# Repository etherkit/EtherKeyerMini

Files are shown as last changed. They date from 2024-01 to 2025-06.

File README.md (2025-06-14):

# EtherKeyer Mini

A simple keyer that does the basic functions that you need.

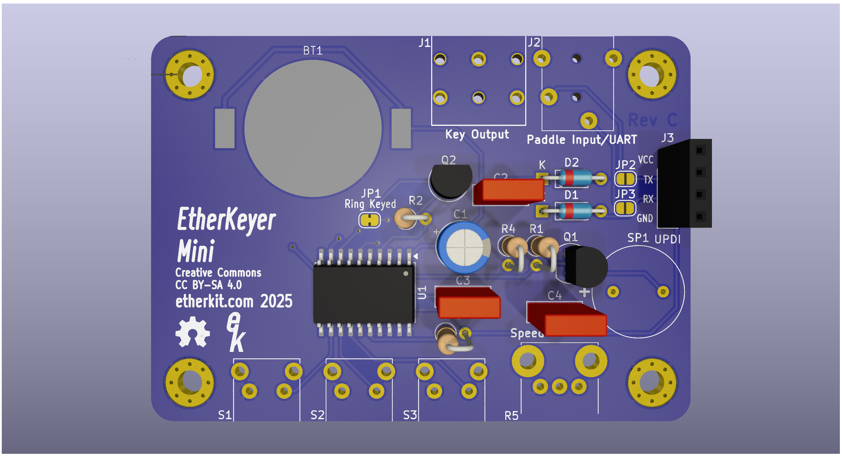
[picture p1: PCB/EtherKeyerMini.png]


## Requirements

In order to program the message memories, change parameters other than the keyer speed, and update the firmware, you'll need a serial terminal that can connect to the 5 V TTL UART on EtherKeyer Mini via the 3.5 mm TRRS paddle jack. The Etherkit UART Adapter board has a USB-C connection for your PC and the requisite 3.5 mm TRRS jack, so that all that you need to connect to EtherKeyer Mini is a 3.5 mm TRRS cable.

A CR2032 lithium coin cell is required for powering EtherKeyer Mini.

## Functions

### Speed Potentiometer

The knob control on the right side of the front of EtherKeyer Mini controls the keyer speed, from a minimum of 5 WPM to a maximum of 40 WPM. This control can be adjusted at any time and responds immediately.

### Pushbuttons

#### Short Press

Cancel any message playback by pressing any button or paddle.

- 1 - Play Message Memory 1
- 2 - Play Message Memory 2
- 3 - Play Message Memory 3

#### Long Press

- 1 - Tune Mode (press any key to exit)
- 2 - Toggle Internal Sidetone
- 3 - Enter/Exit UART Mode

### UART Mode

The format for interacting with EtherKeyer Mini via the UART is very simple. In order to place EtherKeyer Mini into UART mode, press and hold button 3 for at least one second. If your serial terminal is open when you do this, you'll get a greeting from EtherKeyer Mini to let you know it is ready for commands.

Each message memory has a maximum size of 40 characters.

Exit UART mode by pressing and holding button 3 again for at least one second, or issue the ```X:``` command in the serial terminal.

#### Serial Terminal Parameters

19200 baud, send New Line only, no flow control.

#### Query

- ```W?``` - Keyer speed
- ```1?``` - Message memory 1
- ```2?``` - Message memory 2
- ```3?``` - Message memory 3

#### Parameter Set

- ```1:<message>``` - Message memory 1
- ```2:<message>``` - Message memory 2
- ```3:<message>``` - Message memory 3
- ```X:``` - Exit UART Mode
- ```R:``` - Reverse Paddle Terminals
- ```N:``` - Normal Paddle Terminals
- ```A:``` - Set Iambic A Mode
- ```B:``` - Set Iambic B Mode
- ```S:``` - Sidetone On
- ```O:``` - Sidetone Off

## Firmware Updates

__Please see the Requirements section above for the hardware necessary for the UART adapter.__

EtherKeyer Mini uses an ATtiny3226 microcontroller with the Optiboot bootloader pre-installed. You can use load new firmware onto EtherKeyer Mini via a UART adapter connected to the paddle jack (the easiest way to do so is using the Etherkit UART Adapter board with a 3.5 mm TRRS cable). You can also use a standard USB-UART adapter connected to jack J3 to program the ATtiny3226 via UPDI protocol.

Programming via the paddle jack is accomplished using the Arduino IDE using the [megaTinyCore](https://github.com/SpenceKonde/megaTinyCore) board support package. Use [this link](https://github.com/SpenceKonde/megaTinyCore/blob/master/Installation.md) for instructions on how to add this board support package to your Arduino IDE. Once you have added the board support package, connect your UART adapter to your PC. In Arduino IDE, select the "ATtiny3226/1626/826/426 w/Optiboot" as your board and port corresponding to your programming UART adapter. Make sure to set all of the specific board settings in the Tools menu of Arduino IDE to those shown below:

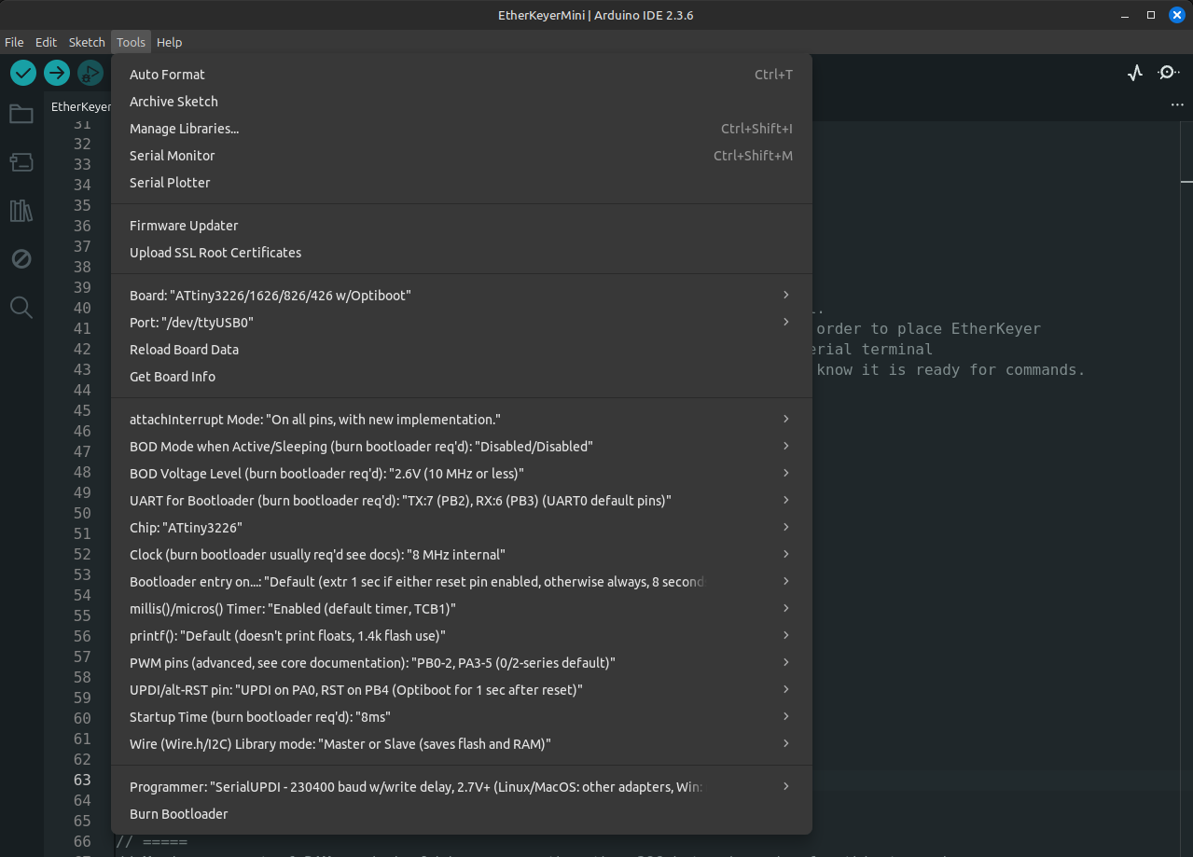
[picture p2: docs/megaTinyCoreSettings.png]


Once you have all of these settings correct, you can load the EtherKeyerMini.ino sketch into the Arduino IDE and then use the Sketch > Upload menu command or use the upload button on the toolbar.

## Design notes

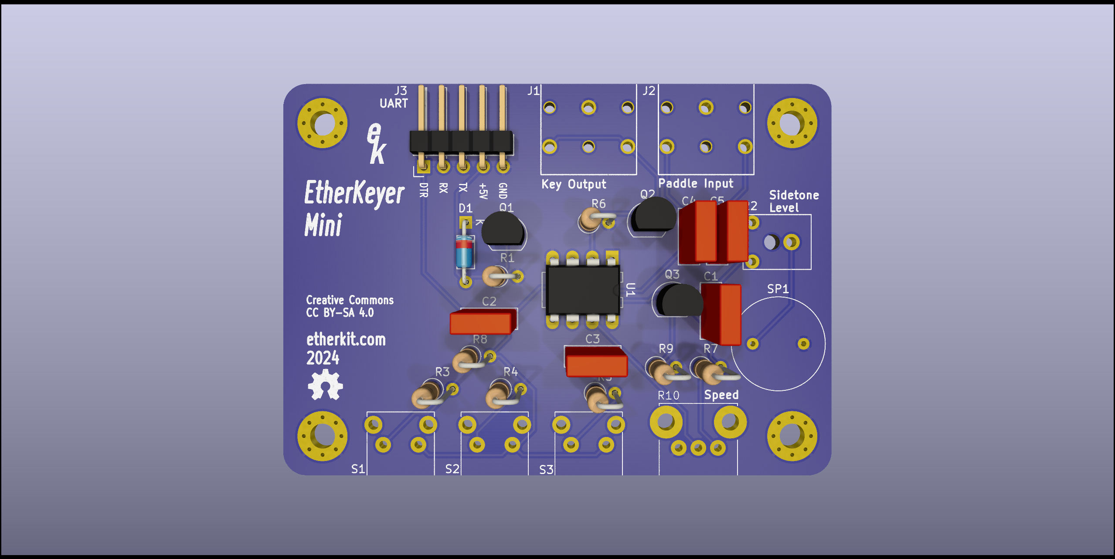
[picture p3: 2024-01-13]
docs/EtherKeyerMini.png

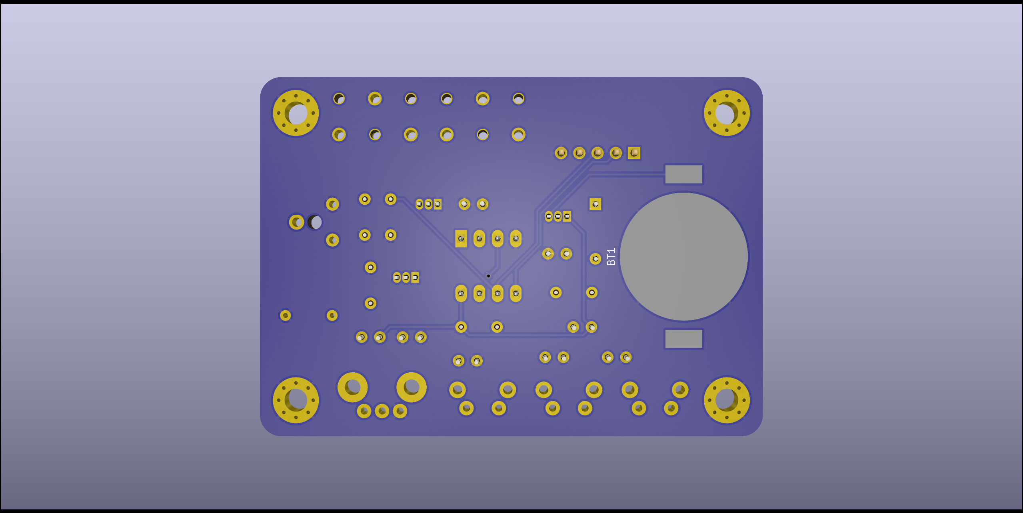
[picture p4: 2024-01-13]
docs/EtherKeyerMiniBack.png

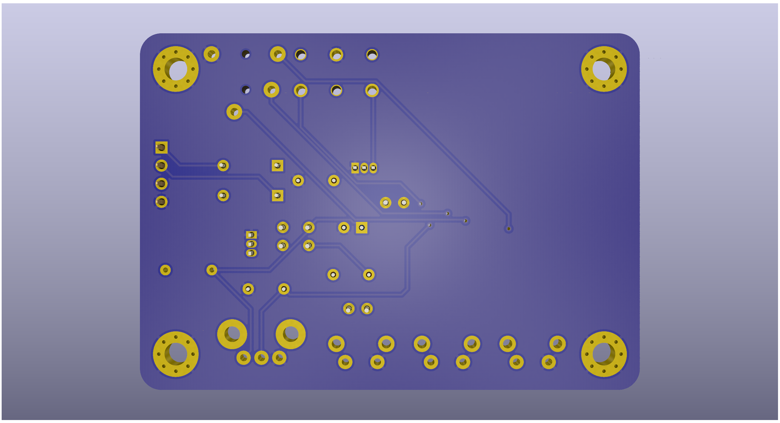
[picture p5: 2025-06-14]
PCB/EtherKeyerMiniBack.png

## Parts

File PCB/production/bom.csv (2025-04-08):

Designator | Footprint | Quantity | Value | LCSC Part #
BT1 | Linx_BAT-HLD-001 | 1 | CR2032
C1 | CP_Radial_D6.3mm_P2.50mm | 1 | 4.7u
C2, C3, C4 | C_Rect_L7.0mm_W2.5mm_P5.00mm | 3 | 100n
D1, D2 | D_DO-35_SOD27_P7.62mm_Horizontal | 2 | 1N5711
J1 | Kycon_STX-3120-3B | 1 | Key Output
J2 | SameSky_SJ-43514 | 1 | Paddle Input/UART
J3 | PinSocket_1x04_P2.54mm_Vertical | 1 | UPDI
Q1, Q2 | TO-92_Inline | 2 | 2N4401
R1, R2, R4 | R_Axial_DIN0207_L6.3mm_D2.5mm_P2.54mm_Vertical | 3 | 10k
R3 | R_Axial_DIN0207_L6.3mm_D2.5mm_P2.54mm_Vertical | 1 | 470
R5 | Bournes_PTV09A | 1 | 1M
S1, S2, S3 | C&K_PTS645VH832LFS | 3 | PUSHBUTTON_TACTILE
SP1 | PUI_AT-1224-TWT-12V-2-R | 1 | Piezo Speaker
U1 | SOIC-20W_7.5x12.8mm_P1.27mm | 1 | ATtiny3226-S

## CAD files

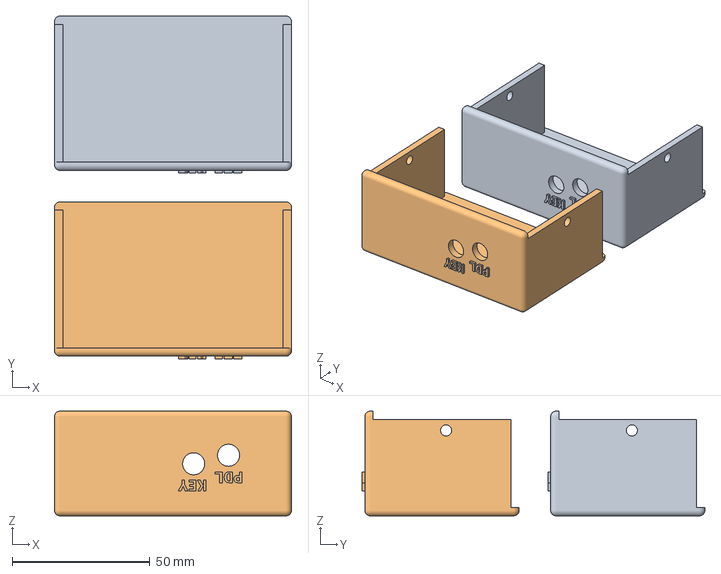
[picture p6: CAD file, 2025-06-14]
mech/EtherKeyerMiniCaseTopNew-Case Top.3mf
86.0 x 124.4 x 38.0 mm

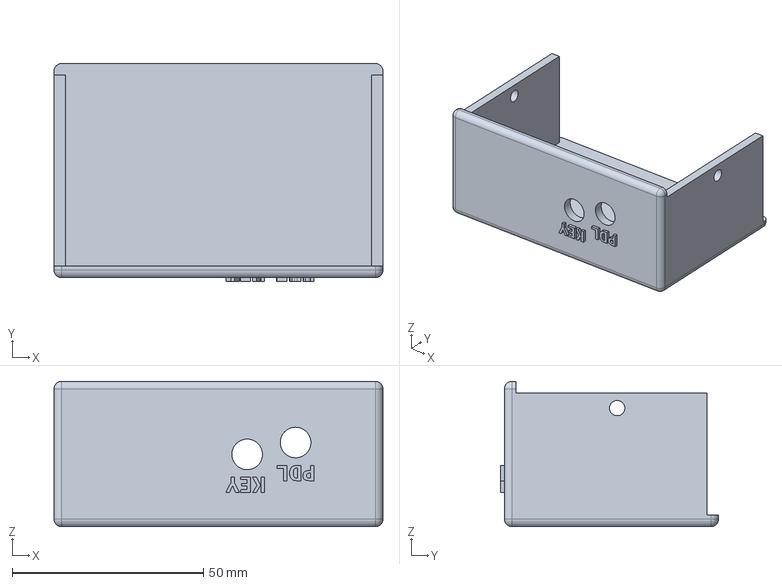
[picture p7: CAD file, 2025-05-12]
mech/EtherKeyerMiniCaseTopNew.FCStd
86.0 x 57.0 x 38.0 mm

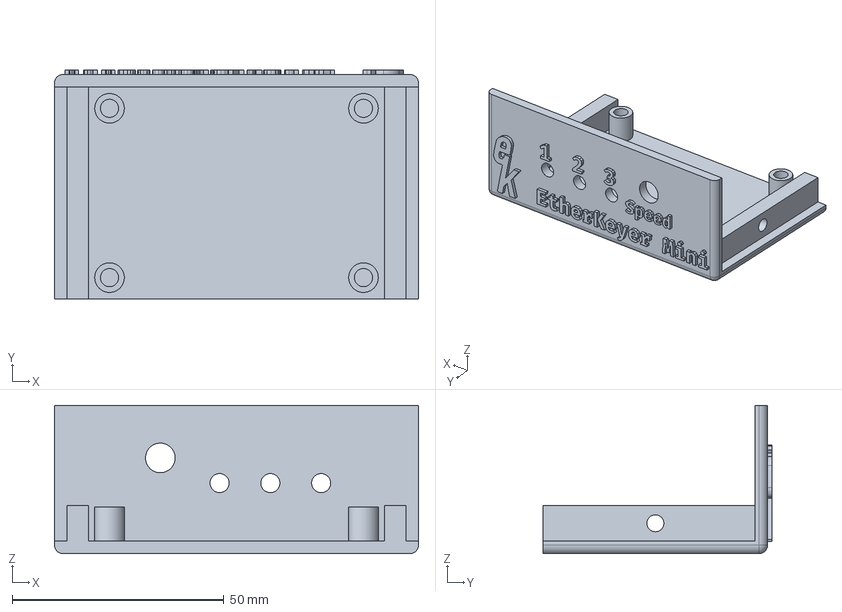
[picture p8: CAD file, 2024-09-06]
mech/EtherKeyerMiniCaseBottomNew.FCStd
86.0 x 54.0 x 35.0 mm

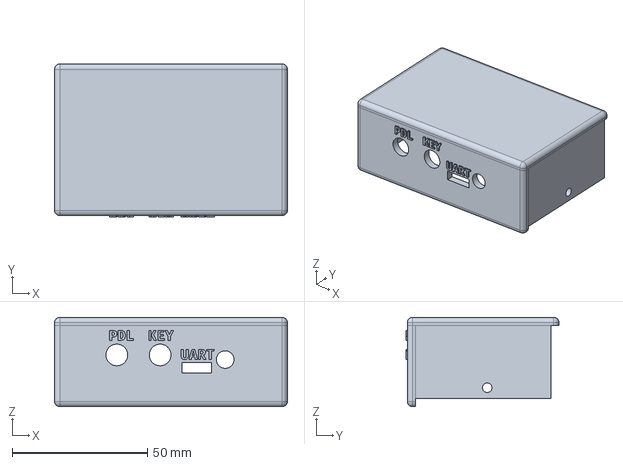
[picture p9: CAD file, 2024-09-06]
mech/EtherKeyerMiniCaseTop.FCStd
86.0 x 56.5 x 33.0 mm

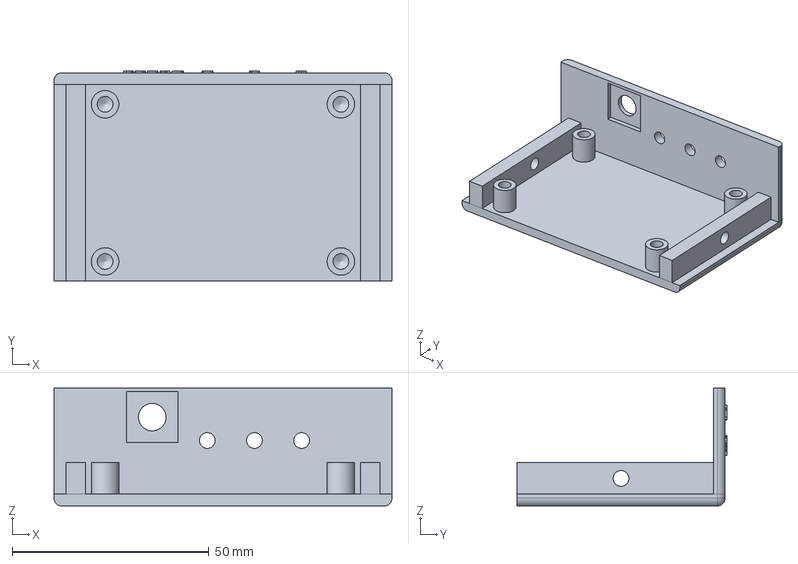
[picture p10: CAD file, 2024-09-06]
mech/EtherKeyerMiniCaseBottom.FCStd
86.0 x 53.5 x 30.0 mm
Case Bottom
ShapeString004
ShapeString005
ShapeString006

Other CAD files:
mech/EtherKeyerMiniCaseBottomNew-Case Bottom.3mf
mech/EtherKeyerMiniCaseBottom.stl
mech/EtherKeyerMiniCaseTop.stl

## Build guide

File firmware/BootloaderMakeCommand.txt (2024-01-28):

make MCU=attiny85 WDTO=2S F_CPU=8000000L BAUD_RATE=57600 SWIO=1 RX=AtmelPB1 TX=AtmelPB0 VBL=1 EEPROM=0 CHIP_ERASE=0 URPROTOCOL=1 BLINK=0 AUTOFRILLS=0,6,4,3,2 NAME=urboot_t85_2s_i8m0_57k6_swio_rxb1_txb0_no-led

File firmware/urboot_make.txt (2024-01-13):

make MCU=attiny85 WDTO=2S F_CPU=8000000L BAUD_RATE=57600 SWIO=1 RX=AtmelPB1 TX=AtmelPB0 VBL=1 PROTECTRESET=1 EEPROM=0 CHIP_ERASE=0 URPROTOCOL=1 BLINK=0 AUTOFRILLS=0,6,4,3,2 NAME=urboot_t85_2s_i8m0_57k6_swio_rxb4_txb3_no-led_pr

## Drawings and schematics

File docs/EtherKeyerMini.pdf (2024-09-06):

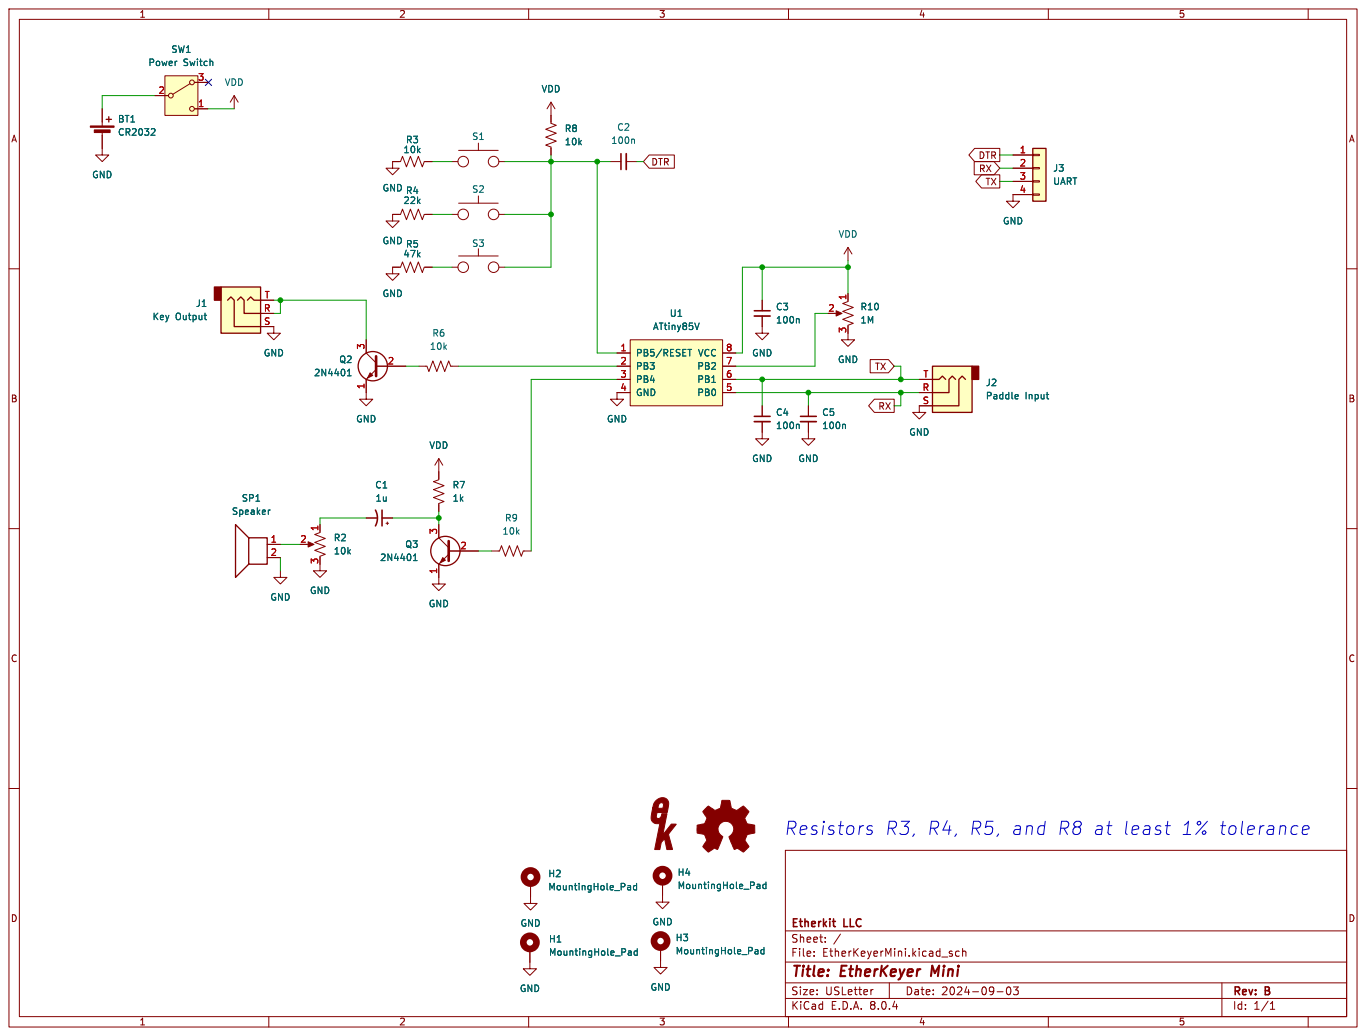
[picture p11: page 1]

TX Resistors R3, R4, R5, and R8 at least 1% tolerance

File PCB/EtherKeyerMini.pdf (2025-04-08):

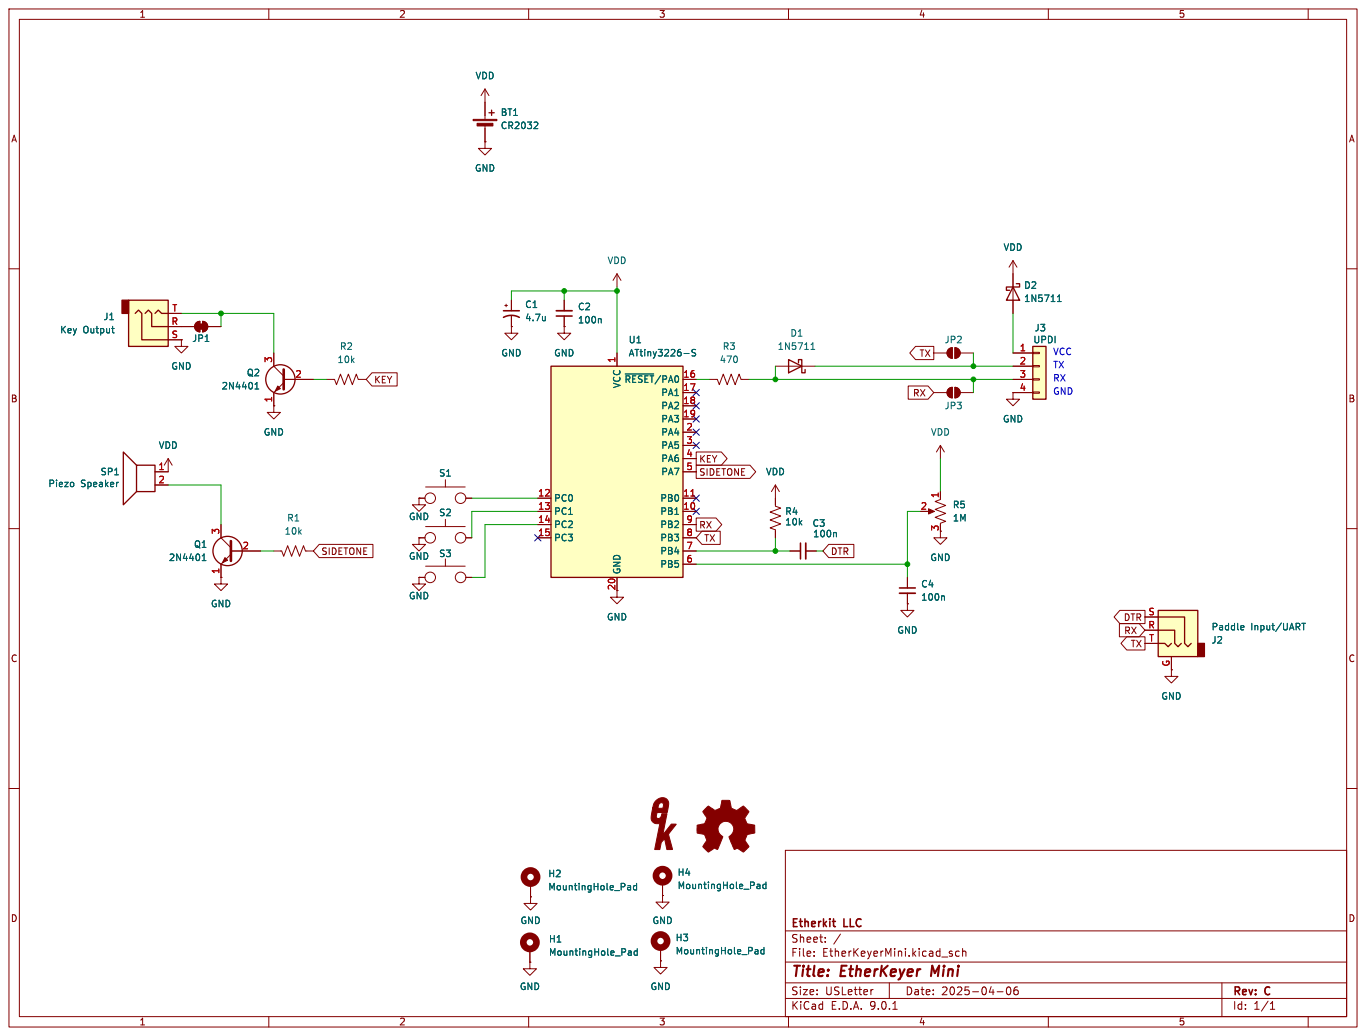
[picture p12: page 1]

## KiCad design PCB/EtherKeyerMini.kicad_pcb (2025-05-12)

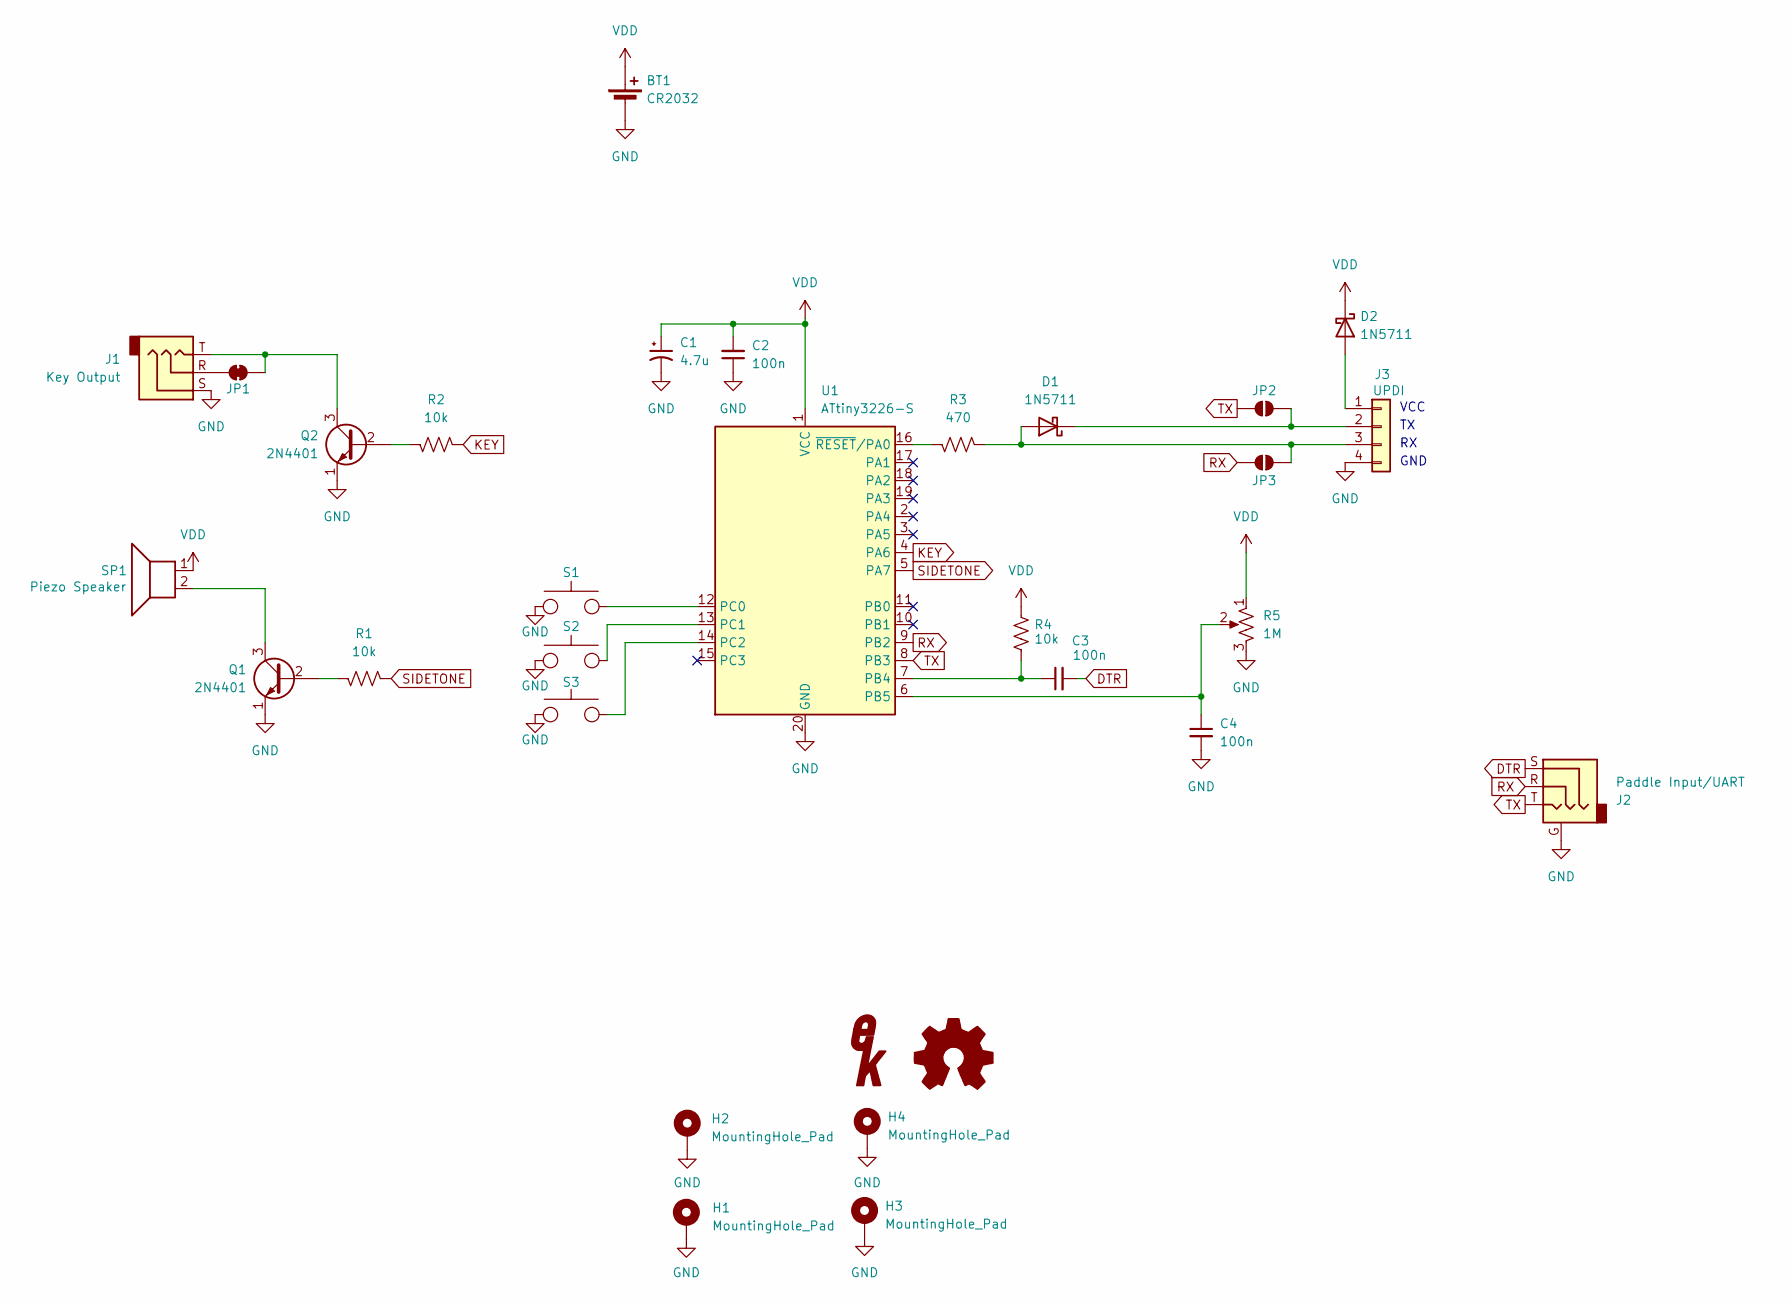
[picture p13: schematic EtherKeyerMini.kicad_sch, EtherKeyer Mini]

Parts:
BT1: CR2032; Linx_BAT-HLD-001
C1: 4.7u; CP_Radial_D6.3mm_P2.50mm
C2, C3, C4: 100n; C_Rect_L7.0mm_W2.5mm_P5.00mm
D1, D2: 1N5711; D_DO-35_SOD27_P7.62mm_Horizontal
G1: LOGO; EtherkitLogoSmall
H1, H2, H3, H4: MountingHole_Pad; MountingHole_3.2mm_M3_Pad_Via
J1: Key Output; Kycon_STX-3120-3B
J2: Paddle Input/UART; SameSky_SJ-43514
J3: UPDI; PinSocket_1x04_P2.54mm_Vertical
JP1: SolderJumper_2_Bridged; SolderJumper-2_P1.3mm_Bridged_RoundedPad1.0x1.5mm
JP2, JP3: SolderJumper_2_Bridged; SolderJumper-2_P1.3mm_Open_RoundedPad1.0x1.5mm
Q1, Q2: 2N4401; TO-92_Inline
R1, R2, R4: 10k; R_Axial_DIN0207_L6.3mm_D2.5mm_P2.54mm_Vertical
R3: 470; R_Axial_DIN0207_L6.3mm_D2.5mm_P2.54mm_Vertical
R5: 1M; Bournes_PTV09A
S1, S2, S3: PUSHBUTTON_TACTILE; C&K_PTS645VH832LFS
SP1: Piezo Speaker; PUI_AT-1224-TWT-12V-2-R
SYM1: Logo_Open_Hardware_Small; OSHWLogo4mm
U1: ATtiny3226-S; SOIC-20W_7.5x12.8mm_P1.27mm

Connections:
DTR: C3.2, J2.S
GND: BT1.2 (-), C1.2, C2.1, C4.2, H1.1, H2.1, H3.1, H4.1, J1.S, J2.G, J3.4, Q1.1 (E), Q2.1 (E), R5.3, S1.1, S2.1, S3.1, U1.20 (GND)
KEY: R2.2, U1.4 (PA6)
unnamed: D1.2 (A), J3.3, JP3.2 (B), R3.2
unnamed: D1.1 (K), J3.2, JP2.2 (B)
unnamed: D2.2 (A), J3.1
unnamed: J1.R, JP1.1 (A)
unnamed: J1.T, JP1.2 (B), Q2.3 (C)
unnamed: Q1.2 (B), R1.1
unnamed: Q1.3 (C), SP1.2
unnamed: Q2.2 (B), R2.1
unnamed: C3.1, R4.2, U1.7 (PB4)
unnamed: C4.1, R5.2, U1.6 (PB5)
unnamed: S1.2, U1.12 (PC0)
unnamed: S2.2, U1.13 (PC1)
unnamed: S3.2, U1.14 (PC2)
unnamed: R3.1, U1.16 (~RESET/PA0)
RX: J2.R, JP3.1 (A), U1.9 (PB2)
SIDETONE: R1.2, U1.5 (PA7)
TX: J2.T, JP2.1 (A), U1.8 (PB3)
VDD: BT1.1 (+), C1.1, C2.2, D2.1 (K), R4.1, R5.1, SP1.1, U1.1 (VCC)

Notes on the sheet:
GND
VCC

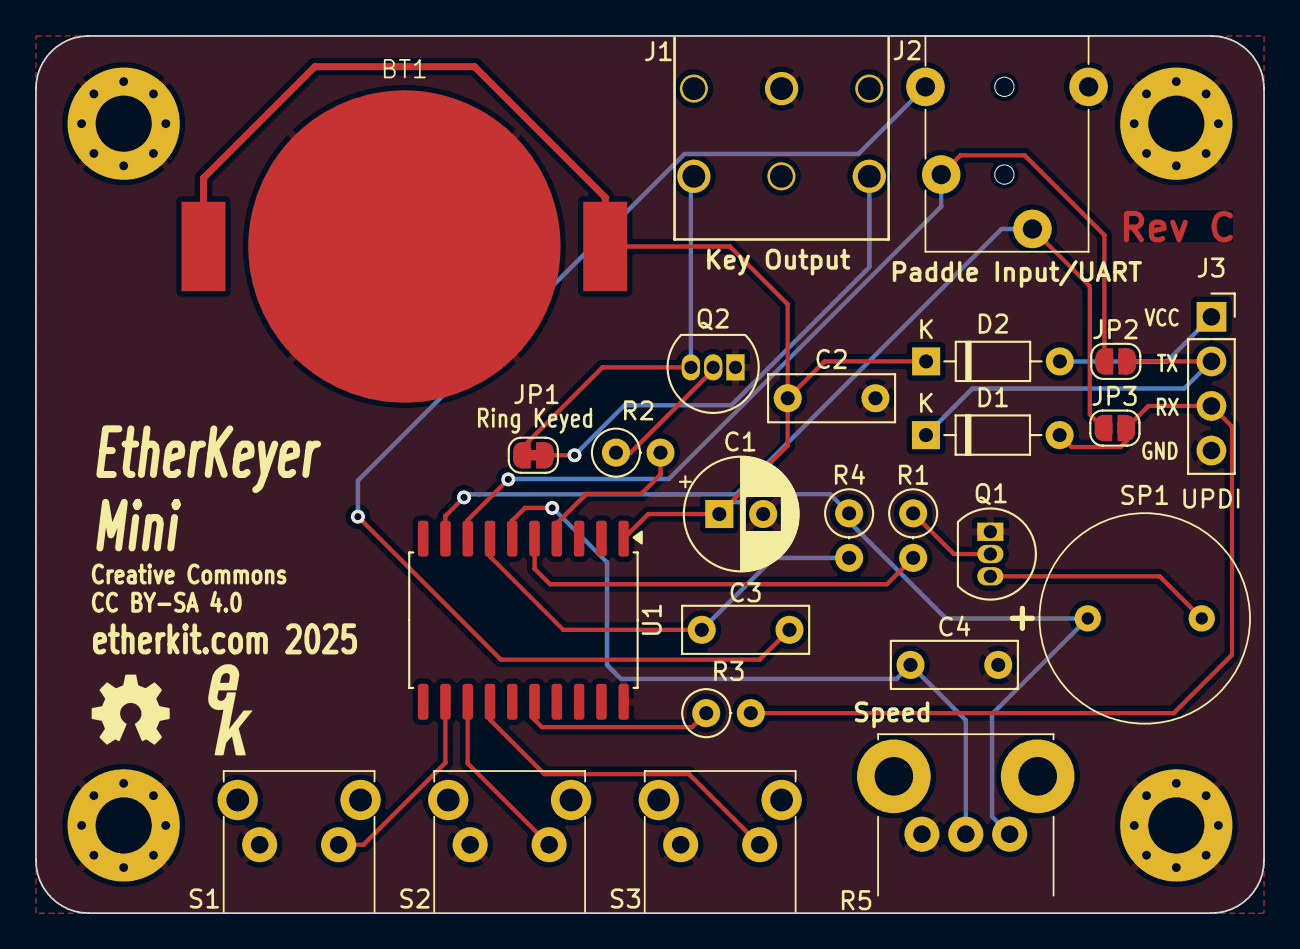
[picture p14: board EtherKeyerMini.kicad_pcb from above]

Board: 2 copper layers, 70.0 x 50.0 mm, 31 parts (0 on the bottom side), 21 nets.

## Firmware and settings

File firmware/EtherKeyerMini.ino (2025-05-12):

// EtherKeyer Mini
// 
// Jason Milldrum, NT7S
// Etherkit LLC
//
// This work is licensed under CC BY-SA 4.0
//
// Last Revision: 11 May 2025
// For Rev C PCB
//
// A basic memory Morse Code keyer for use with paddles.
// Keyer speed is adjustable via potentiometer. Three message memories with dedicated playback
// buttons are provided. Message memory programming and other parameter settings are done via
// serial terminal access at 19200 baud.
//
// Libraries Used
// ==============
// Etherkit Morse (Library Manager)
// Arduino Timer (Library Manager)
//
// Pushbuttons
// ===========
//
// Short Press
// -----------
// Cancel any message playback by pressing any button or paddle.
//
// * 1 - Play Message Memory 1
// * 2 - Play Message Memory 2
// * 3 - Play Message Memory 3
//
// Long Press
// ----------
// * 1 - Tune Mode (press any key to exit)
// * 2 - Toggle Internal Sidetone
// * 3 - Enter/Exit UART Mode
//
// Serial commands
// ===============
// Serial terminal parameters: 19200 baud, send New Line only, no flow control.
// The format for interacting with EtherKeyer via the UART is very simple. In order to place EtherKeyer
// into UART mode, press and hold button 3 for at least one second. If your serial terminal
// is open when you do this, you'll get a greeting from EtherKeyer to let you know it is ready for commands.
//
// Query
// -----
// W?     Keyer speed
// 1?     Message memory 1
// 2?     Message memory 2
// 3?     Message memory 3
//
// Parameter Set
// -------------
// 1:<message>     Message memory 1
// 2:<message>     Message memory 2
// 3:<message>     Message memory 3
// X:              Exit UART Mode
// R:              Reverse Paddle Terminals
// N:              Normal Paddle Terminals
// A:              Set Iambic A Mode
// B:              Set Iambic B Mode
// S:              Sidetone On
// O:              Sidetone Off
//
// Notes
// =====
// Maximum amount of RAM used should be no more than than 386 bytes in order for this to work

#include <stdint.h>
#include <Morse.h>
#include <arduino-timer.h>
#include <EEPROM.h>
#include <avr/interrupt.h>
#include <avr/sleep.h>
#include <avr/power.h>
#include <avr/wdt.h>

#define FIRMWARE_VERSION "11 May 2025"

// Pin defines
#define SPEED_INPUT PIN_PB5
#define PADDLE_RING PIN_PB2  // Typical config, ring == DAH
#define PADDLE_TIP PIN_PB3   // Typical config, tip == DIT
#define BUTTON_S1 PIN_PC0
#define BUTTON_S2 PIN_PC1
#define BUTTON_S3 PIN_PC2
#define KEY_OUTPUT PIN_PA6
#define SIDETONE_OUTPUT PIN_PA7

// Defaults
#define DEFAULT_SIDETONE_FREQ 600
#define DEFAULT_KEYER_SPEED 20

// Limits
#define KEYER_SPEED_LOWER 5
#define KEYER_SPEED_UPPER 40
#define BUTTON_PRESS_SHORT 10
#define BUTTON_PRESS_LONG 1000
#define SLEEP_TIME 3000  // In milliseconds, has to be long enough to not go to sleep during a long button press

// EEPROM Addresses
// Why not just use a struct for all of EEPROM? RAM is too scarce to work with the whole struct at once.
// So, we only load one param at a time. A bit cumbersome and not very foolproof, but we have our limits.
#define EEP_M1_ADDR 0  // Message memory 3 string, 40 chars plus terminator
#define EEP_M2_ADDR 41  // Message memory 3 string, 40 chars plus terminator
#define EEP_M3_ADDR 82  // Message memory 3 string, 40 chars plus terminator
#define EEP_PADDLE_REV 123  // Paddle reverse, 1 byte (uint8_t)
#define EEP_SIDETONE_FREQ 124  // Sidetone frequency, 2 bytes (uint16_t)
#define EEP_SPEED_LOWER 126  // Keyer speed lower limit, 1 byte (uint8_t)
#define EEP_SPEED_UPPER 127  // Keyer speed upper limit, 1 byte (uint8_t)
#define EEP_KEYER_MODE 128  // Keyer mode, 1 byte (uint8_t)
#define EEP_SIDETONE_ON 129  // Sidetone active, 1 byte (uint8_t)

// Enumerations
enum class KeyerState {IDLE, DIT, DAH, DITIDLE, DAHIDLE, CHARSPACE, PLAYBACK, ANNUNCIATE, UART, TUNE};
enum class Button {NONE, S1, S2, S3, S1S2, S2S3, S1S3, HOLD};
enum class Iambic {A, B};

// Global variables
uint32_t keyer_speed = DEFAULT_KEYER_SPEED;
uint16_t sidetone_freq = DEFAULT_SIDETONE_FREQ;
bool paddle_ring_active = false;
bool paddle_tip_active = false;
bool key_down = false;
uint16_t dit_length;
uint32_t button_press_time;
uint32_t sleep_timeout;
KeyerState prev_keyer_state = KeyerState::IDLE;
KeyerState curr_keyer_state = KeyerState::IDLE;
KeyerState next_keyer_state = KeyerState::IDLE;
// Button last_button = Button::NONE;
bool paddle_reverse = false;
Iambic keyer_mode = Iambic::A;
bool sidetone_active = false;


// Object constructors
Timer<2, micros> morse_timer; // create a timer with 2 tasks and microsecond resolution
Timer<2, micros> memory_keyer_timer; // create a timer with 2 tasks and microsecond resolution
Timer<2, millis> state_expire_timer; // create a timer with 2 tasks and millisecond resolution
Morse morse(KEY_OUTPUT, keyer_speed);

ISR(PORTB_PORT_vect) {
  uint8_t flags = PORTB.INTFLAGS;
  PORTB.INTFLAGS = flags; //clear flags
  // if (flags & 0x02) {
  //   //
  // }
  // if (flags & 0x04) {
  //   //
  // }
  reset_sleep_timer();
}

ISR(PORTC_PORT_vect) {
  uint8_t flags = PORTC.INTFLAGS;
  PORTC.INTFLAGS = flags; //clear flags
  // if (flags & 0x02) {
  //   //
  // }
  // if (flags & 0x04) {
  //   //
  // }
  reset_sleep_timer();
}

// Timer Callbacks
// bool process_memory_keyer(void *) {
//   if(curr_keyer_state == KeyerState::PLAYBACK)
//   {
//     morse.update();
//   }

//   return true;
// }

bool process_keyer_sm(void *)
{
  uint16_t speed_pot_adc;
  // static uint32_t button_press_time;
  static Button last_button;

  if(curr_keyer_state == KeyerState::PLAYBACK)
  {
    morse.update();
  }

  // Process speed pot
  speed_pot_adc = analogRead(SPEED_INPUT);
  keyer_speed = (speed_pot_adc * (KEYER_SPEED_UPPER - KEYER_SPEED_LOWER) / 1023) + KEYER_SPEED_LOWER;
  dit_length = (1200 / keyer_speed);
  morse.setWPM(keyer_speed);

  // Process buttons
  Button cur_button = process_button();

  if (cur_button != Button::NONE) // Handle a button press
  {
    if (last_button == Button::NONE) // Short press
    {
      last_button = cur_button;
      button_press_time = millis();
    }
    else if (millis() > (button_press_time + BUTTON_PRESS_LONG) && (last_button != Button::HOLD))  // Long press
    {
      switch(cur_button)
      {
        case Button::S1:
          reset_sleep_timer();
          curr_keyer_state = KeyerState::TUNE;
          keyline_on();
          last_button = Button::HOLD;
          break;
        case Button::S2:
          if (sidetone_active)
          {
            set_sidetone(false);
            tone(SIDETONE_OUTPUT, 400);
            delay(200);
            noTone(SIDETONE_OUTPUT);
          }
          else
          {
            set_sidetone(true);
            tone(SIDETONE_OUTPUT, 1000);
            delay(200);
            noTone(SIDETONE_OUTPUT);
          }
          last_button = Button::HOLD;
          break;
        case Button::S3:
          reset_sleep_timer();
          if (curr_keyer_state == KeyerState::UART)
          {
            exit_uart();
          }
          else
          {
            curr_keyer_state = KeyerState::UART;
            // Toggle the pin modes for UART service
            pinMode(PADDLE_RING, OUTPUT);
            pinMode(PADDLE_TIP, INPUT);
            Serial.begin(19200);
            delay(100);
            Serial.println();
            Serial.println("EtherKeyer Mini");
            Serial.print("Firmware ");
            Serial.println(FIRMWARE_VERSION);
          }
          last_button = Button::HOLD;
          break;
      }
    }
  }
  else
  {
    if (last_button != Button::NONE)  // Check if this is a release
    {
      reset_sleep_timer();
      if ((millis() >= (button_press_time + BUTTON_PRESS_SHORT)) && (millis() < (button_press_time + BUTTON_PRESS_LONG))) // Short press
      {
        if (curr_keyer_state == KeyerState::PLAYBACK || curr_keyer_state == KeyerState::TUNE)  // Cancel playback if button pressed
        {
          morse.reset();
          // digitalWrite(KEY_OUTPUT, LOW);
          keyline_off();
          curr_keyer_state = KeyerState::IDLE;
        }
        else
        {
          curr_keyer_state = KeyerState::PLAYBACK;
          morse.setWPM(keyer_speed);
          send_message(((uint8_t)last_button - 1) * EEP_M2_ADDR);
        }
      }
      // button_press_time = UINT32_MAX;
      last_button = Button::NONE;
    }
  }

  // Process the keyer state machine
  switch (curr_keyer_state)
  {
    case KeyerState::IDLE:
      // Check paddle inputs
      if (paddle_tip_active)
      {
        if (paddle_reverse)
        {
          curr_keyer_state = KeyerState::DAH;
          // prev_keyer_state = KeyerState::DAH;
          state_expire_timer.in(dit_length * 3, ditdah_expire);
        }
        else
        {
          curr_keyer_state = KeyerState::DIT;
          // prev_keyer_state = KeyerState::DIT;
          state_expire_timer.in(dit_length, ditdah_expire);
        }
        prev_keyer_state = KeyerState::IDLE;
        next_keyer_state = KeyerState::IDLE;
        // digitalWrite(KEY_OUTPUT, HIGH);
        keyline_on();
        // state_expire_timer.in(dit_length, ditdah_expire);
      }
      else if (paddle_ring_active)
      {
        if (paddle_reverse)
        {
          curr_keyer_state = KeyerState::DIT;
          // prev_keyer_state = KeyerState::DIT;
          state_expire_timer.in(dit_length, ditdah_expire);
        }
        else
        {
          curr_keyer_state = KeyerState::DAH;
          // prev_keyer_state = KeyerState::DAH;
          state_expire_timer.in(dit_length * 3, ditdah_expire);
        }
        prev_keyer_state = KeyerState::IDLE;
        next_keyer_state = KeyerState::IDLE;
        // digitalWrite(KEY_OUTPUT, HIGH);
        keyline_on();
        // state_expire_timer.in(dit_length * 3, ditdah_expire);
      }
      else
      {
        keyline_off();
      }
      break;
    case KeyerState::DIT:  // Where the squeeze keying happens
      // if (paddle_reverse)
      // {
      //   if (paddle_tip_active)
      //   {
      //     next_keyer_state = KeyerState::DAH;
      //     prev_keyer_state = KeyerState::DIT;
      //   }
      // }
      // else
      // {
      if (keyer_mode == Iambic::A)
      {
        if (paddle_reverse ? paddle_tip_active : paddle_ring_active)
        {
          prev_keyer_state = KeyerState::DIT;
          next_keyer_state = KeyerState::DAH;
        }
        else if (!paddle_ring_active && !paddle_tip_active)
        {
          next_keyer_state = KeyerState::IDLE;
        }
      }
      else if (keyer_mode == Iambic::B)
      {
        if (paddle_reverse ? paddle_tip_active : paddle_ring_active)
        {
          prev_keyer_state = KeyerState::DIT;
          next_keyer_state = KeyerState::DAH;
        }
        else if (!paddle_ring_active && !paddle_tip_active && next_keyer_state == KeyerState::DAH)
        {
          prev_keyer_state = KeyerState::IDLE;
          next_keyer_state = KeyerState::DAH;
        }
      }
        
      // }
      break;
    case KeyerState::DAH:  // Where the squeeze keying happens
      // if (paddle_reverse)
      // {
      //   if (paddle_ring_active)
      //   {
      //     next_keyer_state = KeyerState::DIT;
      //     prev_keyer_state = KeyerState::DAH;
      //   }
      // }
      // else
      // {
      if (keyer_mode == Iambic::A)
      {
        if (paddle_reverse ? paddle_ring_active : paddle_tip_active)
        {

          prev_keyer_state = KeyerState::DAH;
          next_keyer_state = KeyerState::DIT;
        }
        else if (!paddle_ring_active && !paddle_tip_active)
        {
          next_keyer_state = KeyerState::IDLE;
        }
      }
      else if (keyer_mode == Iambic::B)
      {
        if (paddle_reverse ? paddle_ring_active : paddle_tip_active)
        {
          prev_keyer_state = KeyerState::DAH;
          next_keyer_state = KeyerState::DIT;
        }
        else if (!paddle_ring_active && !paddle_tip_active && next_keyer_state == KeyerState::DIT)
        {
          prev_keyer_state = KeyerState::IDLE;
          next_keyer_state = KeyerState::DIT;
        }
      }
      // }
      break;
    case KeyerState::CHARSPACE:
      reset_sleep_timer();
      if (prev_keyer_state == KeyerState::DAH)
      {
        if (paddle_reverse ? paddle_ring_active : paddle_tip_active)
        {
          next_keyer_state = KeyerState::DIT;
        }
      }
      else if (prev_keyer_state == KeyerState::DIT)
      {
        if (paddle_reverse ? paddle_tip_active : paddle_ring_active)
        {
          next_keyer_state = KeyerState::DAH;
        }
      }
      break;
    case KeyerState::PLAYBACK:
      reset_sleep_timer();
      if (morse.busy == false)
      {
        noTone(SIDETONE_OUTPUT);
        curr_keyer_state = KeyerState::IDLE;
      }
      if (sidetone_active)
      {
        if (morse.tx)
        {
          tone(SIDETONE_OUTPUT, DEFAULT_SIDETONE_FREQ);
        }
        else
        {
          noTone(SIDETONE_OUTPUT);
        }
      }
      break;
    case KeyerState::ANNUNCIATE:
      reset_sleep_timer();
      // if (morse.busy == false)
      // {
      //   noTone();
      //   curr_keyer_state = KeyerState::IDLE;
      // }
      // if (morse.tx)
      // {
      //   tone(SIDETONE_OUTPUT, 600);
      // }
      // else
      // {
      //   noTone();
      // }
      break;
    case KeyerState::TUNE:
      reset_sleep_timer();
      break;
    case KeyerState::UART:
      // TODO: UART idle timer to go back to sleep
      reset_sleep_timer();
      if (Serial.available())
      {
        char buf[41];
        char out[41];
        int size = Serial.readBytesUntil('\n', buf, 40);
        buf[size] = '\0'; // Null terminate so it's a string

        if (buf[1] == '?')  // Get parameter
        {
          switch (toupper(buf[0]))
          {
            case '1':
            case '2':
            case '3':
              EEPROM.get((buf[0] - 49) * EEP_M2_ADDR, out);
              Serial.println(out);
              break;
            case 'W':  // Get WPM
              Serial.println(keyer_speed);
              break;
          }
        }
        else if (buf[1] == ':')  // Set parameter
        {
          switch (toupper(buf[0]))
          {
            case 'X':  // Exit UART mode
              exit_uart();
              break;
            case 'R':
              paddle_reverse = 1;
              EEPROM.put(EEP_PADDLE_REV, 1);
              break;
            case 'N':
              paddle_reverse = 0;
              EEPROM.put(EEP_PADDLE_REV, 0);
              break;
            case 'A':
              keyer_mode = Iambic::A;
              EEPROM.put(EEP_KEYER_MODE, keyer_mode);
              break;
            case 'B':
              keyer_mode = Iambic::B;
              EEPROM.put(EEP_KEYER_MODE, keyer_mode);
              break;
            case 'S':
              // sidetone_active = true;
              // EEPROM.put(EEP_SIDETONE_ON, 1);
              set_sidetone(true);
              break;
            case 'O':
              // sidetone_active = false;
              // EEPROM.put(EEP_SIDETONE_ON, 0);
              set_sidetone(false);
              break;
            case '1':
            case '2':
            case '3':
              uint8_t addr = buf[0] - 49;
              // set_message((buf[0] - 49) * EEP_M2_ADDR, buf);
              memmove(buf, buf + 2, 40);
              strupr(buf);
              EEPROM.put(addr * EEP_M2_ADDR, buf);
              // Print it back
              EEPROM.get((addr) * EEP_M2_ADDR, out);
              Serial.print(addr + 1);
              Serial.print(":");
              Serial.println(out);
              break;
          }
        }

        // Clear serial buffer
        memset(buf,0,strlen(buf));
      }
      break;
  }

  return true;
}

bool ditdah_expire(void *)
{
  // digitalWrite(KEY_OUTPUT, LOW);
  keyline_off();
  curr_keyer_state = KeyerState::CHARSPACE;
  state_expire_timer.in(dit_length, charspace_expire);
  return false;
}

static bool charspace_expire(void *)
{
  // if (next_keyer_state == KeyerState::IDLE)
  // {
  //   if (paddle_ring_active)
  //   {
  //     if (paddle_reverse)
  //     {
  //       curr_keyer_state = KeyerState::DIT;
  //     }
  //     else
  //     {
  //       curr_keyer_state = KeyerState::DAH;
  //       // next_keyer_state = KeyerState::DAH;
  //     }
  //     // next_keyer_state = KeyerState::DAH;
  //   }
  //   else if (paddle_tip_active)
  //   {
  //     if (paddle_reverse)
  //     {
  //       curr_keyer_state = KeyerState::DAH;
  //     }
  //     else
  //     {
  //       curr_keyer_state = KeyerState::DIT;
  //       // next_keyer_state = KeyerState::DAH;
  //     }
  //     // next_keyer_state = KeyerState::DIT;
  //   }
  // }
  // prev_keyer_state = KeyerState::IDLE;
  if (next_keyer_state == KeyerState::DIT)
  {
    reset_sleep_timer();
    prev_keyer_state = KeyerState::IDLE;
    curr_keyer_state = KeyerState::DIT;
    next_keyer_state = KeyerState::IDLE;
    // digitalWrite(KEY_OUTPUT, HIGH);
    keyline_on();
    state_expire_timer.in(dit_length, ditdah_expire);
  }
  else if (next_keyer_state == KeyerState::DAH)
  {
    reset_sleep_timer();
    prev_keyer_state = KeyerState::IDLE;
    curr_keyer_state = KeyerState::DAH;
    next_keyer_state = KeyerState::IDLE;
    // digitalWrite(KEY_OUTPUT, HIGH);
    keyline_on();
    state_expire_timer.in(dit_length * 3, ditdah_expire);
  }
  else if (next_keyer_state == KeyerState::DITIDLE)
  {
    reset_sleep_timer();
    prev_keyer_state = KeyerState::IDLE;
    curr_keyer_state = KeyerState::DIT;
    next_keyer_state = KeyerState::IDLE;
    // digitalWrite(KEY_OUTPUT, HIGH);
    keyline_on();
    state_expire_timer.in(dit_length, ditdah_expire);
  }
  else if (next_keyer_state == KeyerState::DAHIDLE)
  {
    reset_sleep_timer();
    prev_keyer_state = KeyerState::IDLE;
    curr_keyer_state = KeyerState::DAH;
    next_keyer_state = KeyerState::IDLE;
    // digitalWrite(KEY_OUTPUT, HIGH);
    keyline_on();
    state_expire_timer.in(dit_length * 3, ditdah_expire);
  }
  else
  {
    // digitalWrite(KEY_OUTPUT, LOW);
    keyline_off();
    curr_keyer_state = KeyerState::IDLE;
    next_keyer_state = KeyerState::IDLE;
  }

  // if (paddle_ring_active)
  // {
  //   digitalWrite(KEY_OUTPUT, HIGH);
  //   next_keyer_state = KeyerState::IDLE;
  //   if (paddle_reverse)
  //   {
  //     curr_keyer_state = KeyerState::DIT;
  //     state_expire_timer.in(dit_length, ditdah_expire);
  //   }
  //   else
  //   {
  //     curr_keyer_state = KeyerState::DAH;
  //     state_expire_timer.in(dit_length * 3, ditdah_expire);
  //   }
  //   // next_keyer_state = KeyerState::DAH;
  // }
  // else if (paddle_tip_active)
  // {
  //   digitalWrite(KEY_OUTPUT, HIGH);
  //   next_keyer_state = KeyerState::IDLE;
  //   if (paddle_reverse)
  //   {
  //     curr_keyer_state = KeyerState::DAH;
  //     state_expire_timer.in(dit_length * 3, ditdah_expire);
  //   }
  //   else
  //   {
  //     curr_keyer_state = KeyerState::DIT;
  //     state_expire_timer.in(dit_length, ditdah_expire);
  //   }
  //   // next_keyer_state = KeyerState::DIT;
  // }
  // else
  // {
  //   digitalWrite(KEY_OUTPUT, LOW);
  //   // PORTB &= ~(1 << PB3);
  //   curr_keyer_state = KeyerState::IDLE;
  //   next_keyer_state = KeyerState::IDLE;
  // }
  
  return false;
}

// Other Functions
void setWPM()
{
  // Dit length in milliseconds is 1200 ms / WPM
	// dit_length = (1200 / keyer_speed);
}

void reset_watchdog()
{
  // wdt_reset();
  // MCUSR = 0;
  // // Setup watchdog to fire every 125 ms
  // WDTCR = bit(WDCE) | bit(WDE) | bit(WDIF) | bit(WDIE) | bit(WDP0)| bit (WDP2);
}

void reset_sleep_timer()
{
  // Reset the sleep timer
  sleep_timeout = millis() + SLEEP_TIME;
}

void send_message(uint8_t addr)
{
  char out[41];
  EEPROM.get(addr, out);
  morse.send(out);
}

void keyline_on()
{
  digitalWriteFast(KEY_OUTPUT, HIGH);
  if (sidetone_active)
  {
    tone(SIDETONE_OUTPUT, DEFAULT_SIDETONE_FREQ);
  }
}

void keyline_off()
{
  digitalWriteFast(KEY_OUTPUT, LOW);
  if (sidetone_active)
  {
    noTone(SIDETONE_OUTPUT);
  }
}

void set_sidetone(uint8_t status)
{
  if (status)
  {
    sidetone_active = true;
    EEPROM.put(EEP_SIDETONE_ON, 1);
  }
  else
  {
    sidetone_active = false;
    EEPROM.put(EEP_SIDETONE_ON, 0);
  }
}

void exit_uart()
{
  curr_keyer_state = KeyerState::IDLE;
  Serial.println("Exit UART");
  Serial.end();
  // Toggle the pin modes for paddle input
  pinMode(PADDLE_RING, INPUT_PULLUP);
  pinMode(PADDLE_TIP, INPUT_PULLUP);
  // last_button = Button::HOLD;
}
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
void loop()
{
  // Tick the various timers
  morse_timer.tick();
  // memory_keyer_timer.tick();
  state_expire_timer.tick();

  // Update inputs and output states
  if (digitalReadFast(PADDLE_RING) == LOW)
  {
    reset_sleep_timer();
    if (curr_keyer_state == KeyerState::PLAYBACK || curr_keyer_state == KeyerState::TUNE)
    {
      morse.reset();
      // digitalWrite(KEY_OUTPUT, LOW);
      keyline_off();
      curr_keyer_state = KeyerState::IDLE;
    }
    else
    {
      paddle_ring_active = true;
    }
  }
  else
  {
    paddle_ring_active = false;
  }

  if (digitalReadFast(PADDLE_TIP) == LOW)
  {
    reset_sleep_timer();
    if (curr_keyer_state == KeyerState::PLAYBACK || curr_keyer_state == KeyerState::TUNE)
    {
      morse.reset();
      // digitalWrite(KEY_OUTPUT, LOW);
      keyline_off();
      curr_keyer_state = KeyerState::IDLE;
    }
    else
    {
      paddle_tip_active = true;
    }
  }
  else
  {
    paddle_tip_active = false;
  }

  // Go to sleep if necessary
  if (millis() > sleep_timeout)
  {
    ADC0.CTRLA &= ~ADC_ENABLE_bm;
    sleep_cpu();
    ADC0.CTRLA |= ADC_ENABLE_bm;
  }
}

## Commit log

2024-01-13 Schematic update
    [EtherKeyerMini.kicad_sch]
2024-01-13 Fix keyer timing in firmware
    [EtherKeyerMini.ino]
2024-01-14 Fix WDT settings in firmware
    [EtherKeyerMini.ino]
2024-01-28 Add BOM, update bootloader and firmware for ATtiny85V
    [EtherKeyerMini.kicad_pcb, EtherKeyerMiniCaseBottom.FCStd, EtherKeyerMiniCaseBottom.stl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]
2024-02-22 Add tune mode, fix reverse keying
    [EtherKeyerMini.ino]
2024-02-23 Fix error in Iambic keying
    [EtherKeyerMini.ino]
2024-07-10 Rev B PCB
    [EtherKeyerMini.kicad_sch, EtherKeyerMiniCaseBottom.FCStd, bom.csv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]
2024-08-14 Fix sleep bug on tune
    [EtherKeyerMini.ino]
2024-08-15 Update schematic, include built firmware
    [EtherKeyerMini.kicad_sch]
2024-08-21 Fix keying bug, move keying detection in to loop
    [EtherKeyerMini.ino]
2024-09-06 Documentation update for Beta
    [EtherKeyerMini.kicad_pcb, EtherKeyerMini.kicad_sch, EtherKeyerMiniCaseBottom.FCStd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]
2025-04-08 Rev C PCB
    [EtherKeyerMini.kicad_pcb, EtherKeyerMini.kicad_sch, bom.csv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]
2025-04-08 Update PDF schematic
2025-04-19 Final firmware for Rev B PCB
2025-05-12 Firmware update to support PCB Rev C
    [EtherKeyerMini.kicad_pcb, EtherKeyerMiniCaseTopNew-Case Top.3mf, EtherKeyerMiniCaseTopNew.FCStd]
2025-06-14 Update documentation to support PCB Rev C
    [EtherKeyerMiniCaseTopNew-Case Top.3mf]
2026-10-19 Migrate the KiCad project to version 10.
    Upgrade the Rev C schematic and board with KiCad 10.0.7 so the files use the current format. Connectivity, placement, and copper are unchanged.
2026-10-20 Stop Mode A trailing element on squeeze release
    Clear dit and dah memory in Mode A when both paddles are open so a
    squeeze edge does not send the same trailing element as Mode B.
    Print the firmware date and active iambic mode on the UART, and store
    the mode in EEPROM as one byte.
2026-10-20 Fix timer to work on ms instead of us for better timing
2026-10-20 Exit UART and tune after an idle timeout
    UART mode reset the sleep timer on every pass, so the ATtiny3226 stayed awake until the operator left the menu. Return to keyer mode after 60 seconds without a received line. Release a forgotten tune key-down after 30 seconds.

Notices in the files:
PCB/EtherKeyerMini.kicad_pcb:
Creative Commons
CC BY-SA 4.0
